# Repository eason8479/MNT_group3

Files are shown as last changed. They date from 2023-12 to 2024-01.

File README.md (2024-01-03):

# Application of IoT technology on 3D-Printer performance



## Division of Work
| 林劭芸 | 褚紘維 | 柯登獻 | 歐子萌 | 林義軒 | Carlos Avramoff |
| --- | --- | --- | --- | --- | --- |
| 設計感測器夾具  | 設計感測器夾具 | 尋找適合的感測器 | 跑3D列印機使用流程 | 安裝硬體設備 | 研究並實現3D列印模型 |
| 開發Jetson Nano | 監控列印機數據 | 焊接感測器 | 收集與處理3D列印機的資料 | 感測器接線佈局 | 收集3D列印機的資料 |
| 開發Dashboard | | 設計感測器夾具 | | 設定GPU Server | |
| 購買感測器 | | 開發Jetson Nano  | | 資料篩選與訓練AI模型 | |
| | | 開發SQL Database | | 收集3D列印機的資料 | |
| | | 開發Dashboard | | | |

| 林劭芸 | 褚紘維 | 柯登獻 | 歐子萌 | 林義軒 | Carlos Avramoff |
| --- | --- | --- | --- | --- | --- |
| Design sensor fixture | Design sensor fixture | Finding the right sensor | Handling procedures for 3d printer usages | Set up the hardware | Research and implementation of 3D models |
| Developing the Jetson Nano | Monitor printer data  | Welding sensor | Assisting in collecting and processing printer data | Connect the ICs to Jetson Nano | Assisting in collecting data |
| Developing the Dashboard | | Design Sensor Fixture | | Set up the GPU server | |
| Buying sensors | | Developing the Jetson Nano | | Data cleaning, and AI model training | |
| | | DevelopingSQL Database | | Helping on collecting data | |
| | | Developing the Dashboard | | | |

## Objective

### 中文
將物聯網技術應用於3D列印機上，例如：

1. 監控底板的水平角度
2. 監控噴頭、底板的溫度
3. 開發回歸模型，開始前預測此次列印是否成功、以及隨時監控預測機台狀況是否正常
4. 在Dashboard中遠端顯示列印機和預測的資訊

### English
To implement the IoT technology in 3D printing manufacturing, such as:

1. Monitor the horizontal angle of the plate
2. Monitor the temperature of the nozzle and the plate
3. Develop regression models, predict the success of the print before starting, and monitor the status of the 3D printer at all times
4. Remote display of printer and forecast information in the Dashboard

## Work

### Requirements
目標是使用邊緣裝置以及感測器收集3D列印機的資訊並顯示在Dashboard上，以及利用收集到的資料用於訓練AI回歸模型預測列印是否成功與機台狀況是否正常。

The goal is to use edge devices and sensors to collect information about the 3D printer and display it on the Dashboard, as well as to use the collected data to train an AI regression model to predict whether a print was successful or not, and whether the printer was in proper condition.

### Hardware
1. Jetson Nano
2. Wireless network interface controller(WNIC)
3. Computer to show dashboard
4. MPU6050
5. MLX90614
6. Wire
7. Solderless breadboard

### Software
1. pip3
2. python3
3. python3 libraries (time, sys, OPCUA)
4. Ubuntu
5. Node-RED Dashboard
6. UaExpert
7. [mpu6050](https://github.com/m-rtijn/mpu6050)
8. [mlx90614](https://github.com/sightsdev/PyMLX90614)

### Result

#### 中文
1. 感測器成功讀到數值
2. 其他裝置可以連線至OPC UA
3. 每2秒可儲存數據到SQL Database裡
4. 成功使用GPU Server並訓練AI回歸模型
5. 資訊可以顯示在Dashboard中

#### English
1. Sensors successfully read the value
2. Other devices can be connected to the OPC UA
3. Save data to SQL Database every 2 seconds
4. Successfully using GPU Server and training AI regression models
5. Information can be displayed in the Dashboard

## Discussion and Suggetion

### Summery

#### 中文
1. 透過感測器收集資料（MPU6050、MLX90614）
2. 將Jetson Nano作為邊緣裝置並使用OPC UA技術與其他裝置連線
3. 使用Node-red儲存3D列印機的資料至SQL Database裡
4. 將SQL Database的資料預處理後，使用GPU Server並訓練AI回歸模型
5. 將資訊顯示在Dashboard中

#### English
1. Data collection via sensors (MPU6050, MLX90614)
2. Use the Jetson Nano as an edge device and connect to other devices using OPC UA technology
3. Use Node-red to store 3D printer data in SQL Database
4. Preprocess data from SQL Database, then use GPU Server and train AI regression model
5. Display information in the Dashboard

### Goals

#### 中文
根據收集的資料；我們可以預測當前狀況是否適合該列印。節省人力並防止錯誤。
-->達成

如果發生錯誤，我們能夠偵測到並使用繼電器或其他方式關閉機器避免浪費，並發送錯誤訊息。
-->部分達成（如果發生錯誤，我們具有偵測的功能）

列印後，回傳一則訊息，以便使用者知道列印已成功結束。
-->達成

#### English
Based on the data we collect; we can predict if the current environment is suitable for this product or not. Saving human hours and preventing errors.
-->ACHIEVED

If an error occurs, we will detect it and use a relay or other ways to shut down the machine to prevent further waste, and send error messages.
-->Some ACHIEVED (If an error occurs, we will detect it.)

After printing, send a message back so the users know the print is finished.
-->ACHIEVED

### Suggestion

#### 中文
1. 可嘗試使用非同步方法將預測功能整合進Jetson Nano裡，減少主機的運算負擔

#### English
1. Try integrating predictions into the Jetson Nano using asynchronous method to reduce the computational burden on the host

## License
Project is licensed under the [MIT](https://github.com/eason8479/MNT_group3/blob/main/LICENSE.txt) license

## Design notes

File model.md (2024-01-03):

# Model 1
- Use for predict the print will success or not
- Inputs and their order for the model are as follow

Name | order
--- | ---
Printing_object | 0
pos_x | 1
pos_y | 2
plate_angel | 3
nozzle_temperture | 4
plate_temperature | 5

- The model will return 1(print will success) ,or 0(print will fail)

> [!WARNING]  
> Due to the lack of the training data, this modle shouldn't be use in any real case.
> Please just take this model as a prove of concept for running duo model on the same server.

# Model 2
- Use for checking current machin is working normally or not
- Inputs and their order for the model are as follow

Name | order
--- | ---
plate_angel_x | 0
plate_angel_y | 1
nozzle_temperture | 2
plate_temperature | 3

- The model will return 1(machine is normal) ,or 0(machine is not normal)

# Use of the code in this folder
- /Model_1: The data for traing model 1 and the code for training/interate with it.
- /Model_2: The data for traing model 2 and the code for training/interate with it.
- Cloud_Computer.ipynb: The code that is running on the cloud server.

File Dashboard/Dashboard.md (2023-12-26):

# Dashboard
這裡主要負責使Dashboard可以讓使用者啟動3D列印機前手動輸入預計要列印的模型資料後，預測此次列印是否成功。以及附有圖表即時顯示3D列印機的機台狀況，並隨時預測目前機台狀況是否正常。

This is what enables the Dashboard to predict the success of a print run after the user manually enters the model data to be printed before starting the 3D printer. A chart shows the status of the 3D printer in real time, and predicts whether the current machine status is good or not.

## Palette
開始使用Node-red前需要先安裝這幾個palette：

You need to install these palettes before you start using Node-red:
```
node-red-contrib-pythonshell
node-red-contrib-ui-led
```

## pip
由於需要安裝「requests」函示庫才能正常執行，因此需要先在Node-red環境中安裝pip。[在Linux安裝pip函式庫可以參照這篇文章](https://docs.aws.amazon.com/zh_tw/elasticbeanstalk/latest/dg/eb-cli3-install-linux.html)，其中3.b步驟需要輸入下列指令：

Since you need to install the "requests" library in order to run it properly, you need to install pip in the Node-red environment first. [You can refer to this article to install the pip library in Linux](https://docs.aws.amazon.com/elasticbeanstalk/latest/dg/eb-cli3-install-linux.html), where step 3.b requires the following commands:
```
export PATH=${PATH}:/usr/src/node-red/.local/bin
```

###### 版本號：v1.0.0

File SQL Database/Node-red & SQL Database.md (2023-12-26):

# Node-red & SQL Database
這裡主要負責讓筆電使用Node-Red接收OPC UA的資料並資料處理儲存於SQL Database裡。其中一個方法節點需要手動調整參數。

This is where Laptop uses Node-Red to receive OPC UA data and process the data to be stored in SQL Database. One of the function nodes requires manual parameter adjustment.

## SQL Database Structure
| Print No | Nozzle Temperature| Plate Temperature | X-axis Angle | Y-axis Angle | X | Y | Model | Time | Successful |
| --- | --- | --- | --- | --- | --- | --- | --- | --- | --- |
|  |  |  |  |  |  |  |  |  |  |

列印時需要手動輸入以下四個參數：

The following four parameters need to be entered manually when printing:
1. Print No
2. X
3. Y
4. Model

## Check for Successful
另一個流則是在成品完成後，主觀認定是否列印成功。其中一個方法節點需要手動調整列印編號以及成功欄位的布林值。

The other flow is to subjectively determine whether the product is successful or not after finishing work. One of the function nodes requires manual adjustment of the Print No and Boolean value of the Successful column.

###### 版本號：v1.0.0

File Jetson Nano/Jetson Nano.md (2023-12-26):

# Jetson Nano
這裡主要負責Jetson Nano利用OPC UA將感測器讀到的資訊發布出去。理論上Jetson Nano在整個流程中只需要執行一個main檔而已。

This is where the Jetson Nano publishes information read from the sensors using OPC UA. Theoretically, Jetson Nano only needs to execute one main file in the whole process.

## Jetson Nano Initialization Environment
```
sudo pip3 install smbus2
sudo pip3 install crcmod
```

## Things to do before running main.py
**每次**要開啟main.py前**都要**執行下列步驟，否則會出錯！

**Every time** you start main.py you **must do** the following steps before you start it, otherwise you will get an error!
```
cd /sys/bus/i2c/devices/i2c-0
sudo vi bus_clk_rate
```

接著將檔案裡頭的數字改成：

Then change the number in the file to:
```
100000
```

:::info
### How to use vi the text editor
開啟vi編輯器後按下「INSERT」鍵就可編輯檔案。儲存檔案時按「ESC」後輸入「:wq」就可退回指令介面。

Open vi the text editor and then press "INSERT" key to edit the file. When saving a file, press "ESC" and enter ":wq" to return to the command interface.
:::

## Sensor Wiring
MPU6050和量測底板的MLX90614使用I2C Bus 0，量測噴頭的MLX90614使用I2C Bus 1。

MPU6050 and MLX90614 for measuring nozzle use I2C Bus 0, and the MLX90614 for measuring plate uses I2C Bus 1.

## Function "linear_adjustment"
使用此方法可以讓感測器讀值調整至正確的溫度。使用時需要輸入兩個參數，第一個是理想上應該要讀到的數值，第二個是實際上讀到的**最大值**。建議在開始讀值前使用此方法。

Use this function to adjust the sensor reading to the correct temperature. There are two parameters that need to be entered, the first is the value that should ideally be read and the second is the **maximum value** that actually is read. It is recommended to use this function before starting to read values.

```python
def linear_adjustment(self, ideal=1, real=1)
```

###### 版本號：v1.0.0

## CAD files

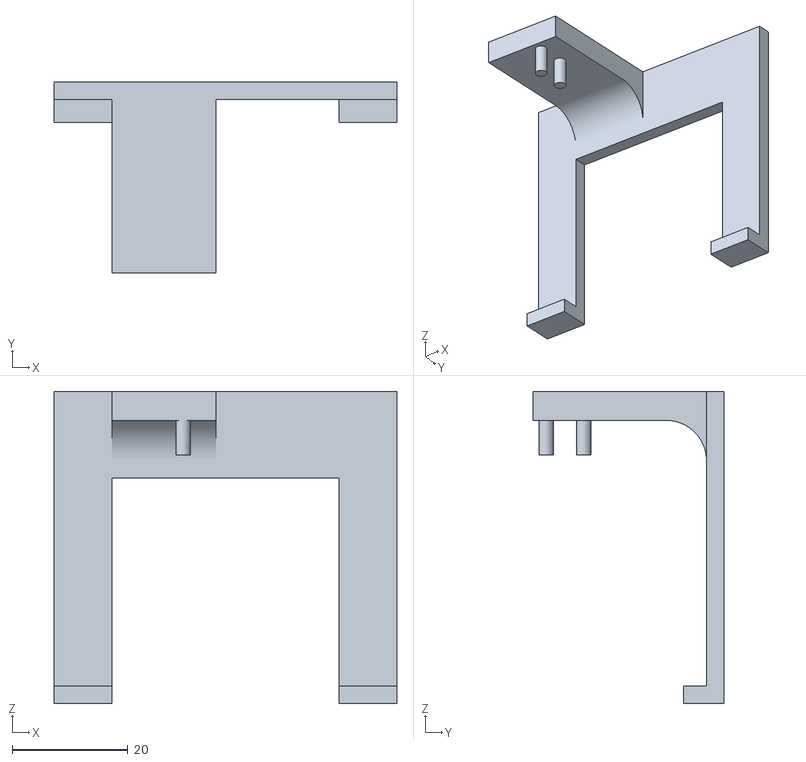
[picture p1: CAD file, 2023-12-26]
Sensor Fixture/hook_5.stl
59.4 x 33.0 x 54.0

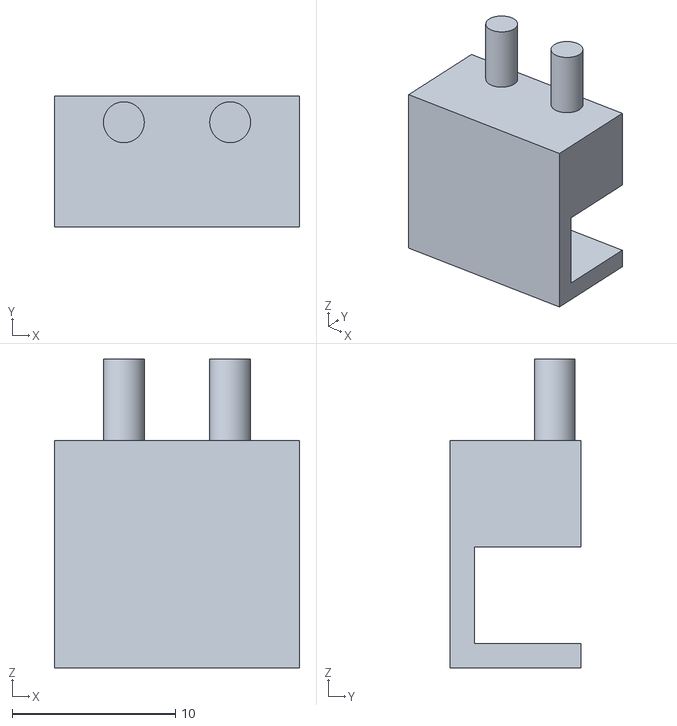
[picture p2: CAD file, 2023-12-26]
Sensor Fixture/clamp_1.stl
15.0 x 8.00 x 18.9

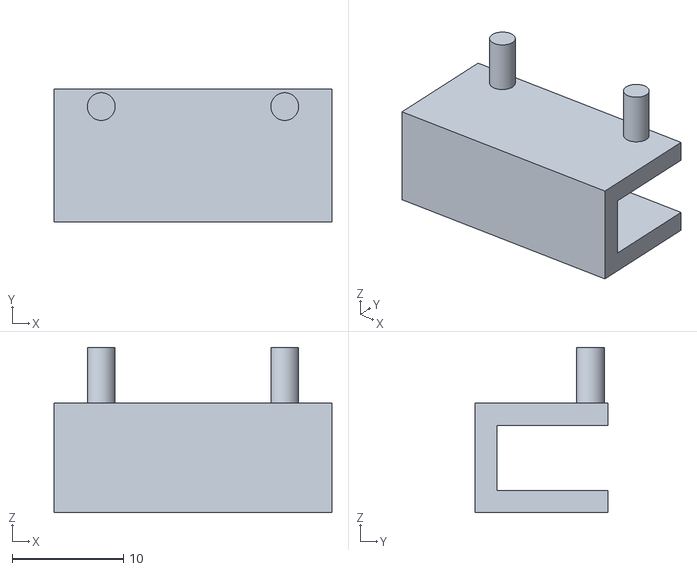
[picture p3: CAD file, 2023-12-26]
Sensor Fixture/clamp_2.stl
25.0 x 12.0 x 14.9

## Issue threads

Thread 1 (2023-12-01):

To-do list

eason8479, 2023-12-01:
# Things need to find
- [ ] find thermo sensor
- [ ] find a relay (or any thing that can turn off the machine)
- [ ] find print model (tiny, had a range of defculity, about 4-5 different models )

# Model
input for model
- [ ] x cord
- [ ] y cord
- [ ] base plate temp
- [ ] plate levle
- [ ] nozel temp

output
- [ ]succes or fail

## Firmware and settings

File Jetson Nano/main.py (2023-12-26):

import sys
sys.path.insert(0, "..")
import time
from mpu6050 import mpu6050
from mlx90614 import MLX90614

from opcua import ua, Server

if __name__ == "__main__":

    # setup our server
    server = Server()
    server.set_endpoint("opc.tcp://0.0.0.0:4840/Team3/")

    # setup our own namespace, not really necessary but should as spec
    uri = "https://ncueeclass.ncu.edu.tw/course/23174"
    idx = server.register_namespace(uri)

    # get Objects node, this is where we should put our nodes
    objects = server.get_objects_node()

    # populating our address space
    myobj_angle = objects.add_object(idx, "angle")
    angle_x = myobj_angle.add_variable(idx, "angle_x", 0.1)
    angle_y = myobj_angle.add_variable(idx, "angle_y", 0.1)
    myobj_temp = objects.add_object(idx, "temp")
    nozzle_temp = myobj_temp.add_variable(idx, "nozzle_temp", 0.1)
    plate_temp = myobj_temp.add_variable(idx, "plate_temp", 0.1)
    angle_x.set_writable()
    angle_y.set_writable()
    nozzle_temp.set_writable()
    plate_temp.set_writable()

    # starting!
    server.start()

    try:
        mpu = mpu6050(0x68)
        sensor = MLX90614(1, address=0x5A)
        plateSensor = MLX90614(0, address=0x5A)
        sensor.linear_adjustment(215, 215)
        plateSensor.linear_adjustment(70, 70)
        while (True):
            time.sleep(2)
            angle_data = mpu.get_angle_data()
            angle_x.set_value(angle_data['x'])
            angle_y.set_value(angle_data['y'])
            nozzle_temp.set_value(sensor.get_obj_temp())
            plate_temp.set_value(plateSensor.get_obj_temp())

    finally:
        # close connection, remove subcsriptions, etc
        server.stop()

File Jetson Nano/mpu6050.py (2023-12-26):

import numpy as np
import smbus

class mpu6050:

    # Global Variables
    GRAVITIY_MS2 = 9.80665
    address = None
    bus = None

    # Scale Modifiers
    ACCEL_SCALE_MODIFIER_2G = 16384.0
    ACCEL_SCALE_MODIFIER_4G = 8192.0
    ACCEL_SCALE_MODIFIER_8G = 4096.0
    ACCEL_SCALE_MODIFIER_16G = 2048.0

    GYRO_SCALE_MODIFIER_250DEG = 131.0
    GYRO_SCALE_MODIFIER_500DEG = 65.5
    GYRO_SCALE_MODIFIER_1000DEG = 32.8
    GYRO_SCALE_MODIFIER_2000DEG = 16.4

    # Pre-defined ranges
    ACCEL_RANGE_2G = 0x00
    ACCEL_RANGE_4G = 0x08
    ACCEL_RANGE_8G = 0x10
    ACCEL_RANGE_16G = 0x18

    GYRO_RANGE_250DEG = 0x00
    GYRO_RANGE_500DEG = 0x08
    GYRO_RANGE_1000DEG = 0x10
    GYRO_RANGE_2000DEG = 0x18

    FILTER_BW_256=0x00
    FILTER_BW_188=0x01
    FILTER_BW_98=0x02
    FILTER_BW_42=0x03
    FILTER_BW_20=0x04
    FILTER_BW_10=0x05
    FILTER_BW_5=0x06

    # MPU-6050 Registers
    PWR_MGMT_1 = 0x6B
    PWR_MGMT_2 = 0x6C

    ACCEL_XOUT0 = 0x3B
    ACCEL_YOUT0 = 0x3D
    ACCEL_ZOUT0 = 0x3F

    TEMP_OUT0 = 0x41

    GYRO_XOUT0 = 0x43
    GYRO_YOUT0 = 0x45
    GYRO_ZOUT0 = 0x47

    ACCEL_CONFIG = 0x1C
    GYRO_CONFIG = 0x1B
    MPU_CONFIG = 0x1A

    def __init__(self, address, bus=0):
        self.address = address
        self.bus = smbus.SMBus(bus)
        # Wake up the MPU-6050 since it starts in sleep mode
        self.bus.write_byte_data(self.address, self.PWR_MGMT_1, 0x00)

    # I2C communication methods

    def read_i2c_word(self, register):
        """Read two i2c registers and combine them.
        register -- the first register to read from.
        Returns the combined read results.
        """
        # Read the data from the registers
        high = self.bus.read_byte_data(self.address, register)
        low = self.bus.read_byte_data(self.address, register + 1)

        value = (high << 8) + low

        if (value >= 0x8000):
            return -((65535 - value) + 1)
        else:
            return value

    # MPU-6050 Methods

    def get_temp(self):
        """Reads the temperature from the onboard temperature sensor of the MPU-6050.
        Returns the temperature in degrees Celcius.
        """
        raw_temp = self.read_i2c_word(self.TEMP_OUT0)

        # Get the actual temperature using the formule given in the
        # MPU-6050 Register Map and Descriptions revision 4.2, page 30
        actual_temp = (raw_temp / 340.0) + 36.53

        return actual_temp

    def set_accel_range(self, accel_range):
        """Sets the range of the accelerometer to range.
        accel_range -- the range to set the accelerometer to. Using a
        pre-defined range is advised.
        """
        # First change it to 0x00 to make sure we write the correct value later
        self.bus.write_byte_data(self.address, self.ACCEL_CONFIG, 0x00)

        # Write the new range to the ACCEL_CONFIG register
        self.bus.write_byte_data(self.address, self.ACCEL_CONFIG, accel_range)

    def read_accel_range(self, raw = False):
        """Reads the range the accelerometer is set to.
        If raw is True, it will return the raw value from the ACCEL_CONFIG
        register
        If raw is False, it will return an integer: -1, 2, 4, 8 or 16. When it
        returns -1 something went wrong.
        """
        raw_data = self.bus.read_byte_data(self.address, self.ACCEL_CONFIG)

        if raw is True:
            return raw_data
        elif raw is False:
            if raw_data == self.ACCEL_RANGE_2G:
                return 2
            elif raw_data == self.ACCEL_RANGE_4G:
                return 4
            elif raw_data == self.ACCEL_RANGE_8G:
                return 8
            elif raw_data == self.ACCEL_RANGE_16G:
                return 16
            else:
                return -1

    def get_accel_data(self, g = False):
        """Gets and returns the X, Y and Z values from the accelerometer.
        If g is True, it will return the data in g
        If g is False, it will return the data in m/s^2
        Returns a dictionary with the measurement results.
        """
        x = self.read_i2c_word(self.ACCEL_XOUT0)
        y = self.read_i2c_word(self.ACCEL_YOUT0)
        z = self.read_i2c_word(self.ACCEL_ZOUT0)

        accel_scale_modifier = None
        accel_range = self.read_accel_range(True)

        if accel_range == self.ACCEL_RANGE_2G:
            accel_scale_modifier = self.ACCEL_SCALE_MODIFIER_2G
        elif accel_range == self.ACCEL_RANGE_4G:
            accel_scale_modifier = self.ACCEL_SCALE_MODIFIER_4G
        elif accel_range == self.ACCEL_RANGE_8G:
            accel_scale_modifier = self.ACCEL_SCALE_MODIFIER_8G
        elif accel_range == self.ACCEL_RANGE_16G:
            accel_scale_modifier = self.ACCEL_SCALE_MODIFIER_16G
        else:
            print("Unkown range - accel_scale_modifier set to self.ACCEL_SCALE_MODIFIER_2G")
            accel_scale_modifier = self.ACCEL_SCALE_MODIFIER_2G

        x = x / accel_scale_modifier
        y = y / accel_scale_modifier
        z = z / accel_scale_modifier

        if g is True:
            return {'x': x, 'y': y, 'z': z}
        elif g is False:
            x = x * self.GRAVITIY_MS2
            y = y * self.GRAVITIY_MS2
            z = z * self.GRAVITIY_MS2
            return {'x': x, 'y': y, 'z': z}

    def set_gyro_range(self, gyro_range):
        """Sets the range of the gyroscope to range.
        gyro_range -- the range to set the gyroscope to. Using a pre-defined
        range is advised.
        """
        # First change it to 0x00 to make sure we write the correct value later
        self.bus.write_byte_data(self.address, self.GYRO_CONFIG, 0x00)

        # Write the new range to the ACCEL_CONFIG register
        self.bus.write_byte_data(self.address, self.GYRO_CONFIG, gyro_range)

    def set_filter_range(self, filter_range=FILTER_BW_256):
        """Sets the low-pass bandpass filter frequency"""
        # Keep the current EXT_SYNC_SET configuration in bits 3, 4, 5 in the MPU_CONFIG register
        EXT_SYNC_SET = self.bus.read_byte_data(self.address, self.MPU_CONFIG) & 0b00111000
        return self.bus.write_byte_data(self.address, self.MPU_CONFIG,  EXT_SYNC_SET | filter_range)

    def read_gyro_range(self, raw = False):
        """Reads the range the gyroscope is set to.
        If raw is True, it will return the raw value from the GYRO_CONFIG
        register.
        If raw is False, it will return 250, 500, 1000, 2000 or -1. If the
        returned value is equal to -1 something went wrong.
        """
        raw_data = self.bus.read_byte_data(self.address, self.GYRO_CONFIG)
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

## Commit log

2023-12-02 訓練ai的部份會用到的code(by義軒)
2023-12-13 Create JetsonNano Branch
2023-12-13 Debug JetsonNano v1-dev
    因為還沒測試過，有可能需要再做修正。目前不確定的項目有：I2C資料是否會撞在一起、MLX90614和MLX90615程式碼是否能夠成功執行、水平角度的數值是否符合預期等。
    Because it has not been tested yet, it is possible that further corrections will be required. Currently, there are some uncertainties: whether the I2C data will conflict, whether the MLX90614 and MLX90615 program codes can be executed successfully, whether the value of the level angle is as expected, and so on.
    [main.py, mlx90614.py, mlx90615.py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]
2023-12-14 Create README.md
    我把之後的計畫打上來，包括12/12討論的內容，以及後我想的一些內容
2023-12-14 Debug JetsonNano v2-dev
    修正求角度時的格式錯誤。
    Fixing issues during angle finding.
    [main.py, mpu6050.py]
2023-12-14 Debug JetsonNano v2-dev
    修正x軸角度顯示方向相反的問題。
    Fixed the issue that x-axis angle is displayed in the opposite direction.
    [mpu6050.py]
2023-12-15 Debug JetsonNano v2-dev
    現在傾斜角度基於Cardan Angle。
    The tilt angle is now based on Cardan Angle.
2023-12-18 Debug JetsonNano v2-dev
    目前預計量測底板和傾斜角使用I2C Bus 1、量測噴頭使用I2C Bus 0。
    Currently, it's assumed that I2C Bus 1 will be used to measure the plate and the level angle, and I2C Bus 0 will be used to measure the nozzle.
2023-12-18 Debug JetsonNano v3-dev
    新增查詢功能以及繼電器腳位輸出。
    Add Inquiry and Relay Pin Outputs.
2023-12-19 Debug JetsonNano v3-dev
    讓程式碼更加簡潔以及調整一些參數。
    Make the code more clean and adjust some parameters.
2023-12-19 Debug SQLDatabase v1-dev
    新增存入資料的Node-red flow，以及輸入列印是否成功的flow。
    Added a Node-red flow for storing data, and a flow for inputting whether printing is successful or not.
2023-12-20 Debug JetsonNano v3-dev
    更新使用指南避免之後使用上又報錯。
    Update the user guide to avoid future errors.
    [mpu6050.py]
2023-12-20 Release JetsonNano v1.0.0-beta
    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
    [mpu6050.py]
2023-12-21 Debug Dashboard v1-dev
    新增手動輸入資料並查詢是否將列印成功的部分。
    Added a new part for manually entering data and checking if it will be printed successfully.
2023-12-22 Debug JetsonNano v4-dev
    新增線性調整使感測器讀到正確的數值。
    Add a linear adjustment to make the sensor read correct values.
    [main.py, mlx90614.py]
2023-12-25 Release JetsonNano v1.0.0-beta
    新增提供線性調整的方法。
    Add a function that provides linear adjustment.
2023-12-25 Debug SQLDatabase v2-dev
    修正Database意外地儲存到OPC UA伺服器初始化的資料。
    Fixed Database accidentally storing data from OPC UA server initialization.
2023-12-25 Debug Dashboard v2-dev
    新增顯示現在機台狀態、過去指定時間內的狀態，以及顯示預測目前機台狀態是否可以列印成功。
    Add a display that shows the current 3D printer status, the status for the past specified time, and a display that predicts whether the current 3D printer status can be printed successfully.
2023-12-26 add data_1.csv
    [data_1.csv]
2023-12-26 Debug Dashboard v2-dev
    更新url。
    Update url.
2023-12-26 Release JetsonNano v1.0.0-beta
    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
2023-12-26 Release JetsonNano v1.0.0-beta
2023-12-26 Release v1.0.0
    修復一些錯誤以及更新使用指南。
    Fixed some bugs and updated the user guide.
2023-12-26 Release v1.0.0
    移除預測功能並精簡程式碼。
    Remove predictive features and streamline code.
2023-12-26 Release v1.0.0
    更新Database。
    Update Database.
2023-12-26 Release v1.0.0
    更改README.md的內容、新增授權條款、新增夾具檔案。
    Change the content of README.md, add new license file, add new fixture files.
    [clamp_1.stl, clamp_2.stl, hook_5.stl]
